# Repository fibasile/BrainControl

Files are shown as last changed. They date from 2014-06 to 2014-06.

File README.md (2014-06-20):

BrainControl
============

Arduino Mind Controlled Robot




Bill of materials
-----------------

- Arduino UNO + Arduino PRO Mini
- MindWave Mobile Bluetooth EEG Headset
- Adafruit Neopixel Ring
- Adafruit LED Matrix
- BlueSmirf Silver Bluetooth
- Pololu Zumo Shield

You can find the PCB schematics in the hardware folder along with files for milling.
You can also build this as a breadboard.

Plans for the lasercut box are included in PDF Format.

Finally the sketches BrainControl and RobotControl must be flashed to the two Arduinos.

License
-------

The MIT License (MIT)

Copyright (c) 2014 Fiore Basile

Permission is hereby granted, free of charge, to any person obtaining a copy
of this software and associated documentation files (the "Software"), to deal
in the Software without restriction, including without limitation the rights
to use, copy, modify, merge, publish, distribute, sublicense, and/or sell
copies of the Software, and to permit persons to whom the Software is
furnished to do so, subject to the following conditions:

The above copyright notice and this permission notice shall be included in
all copies or substantial portions of the Software.

THE SOFTWARE IS PROVIDED "AS IS", WITHOUT WARRANTY OF ANY KIND, EXPRESS OR
IMPLIED, INCLUDING BUT NOT LIMITED TO THE WARRANTIES OF MERCHANTABILITY,
FITNESS FOR A PARTICULAR PURPOSE AND NONINFRINGEMENT. IN NO EVENT SHALL THE
AUTHORS OR COPYRIGHT HOLDERS BE LIABLE FOR ANY CLAIM, DAMAGES OR OTHER
LIABILITY, WHETHER IN AN ACTION OF CONTRACT, TORT OR OTHERWISE, ARISING FROM,
OUT OF OR IN CONNECTION WITH THE SOFTWARE OR THE USE OR OTHER DEALINGS IN
THE SOFTWARE.

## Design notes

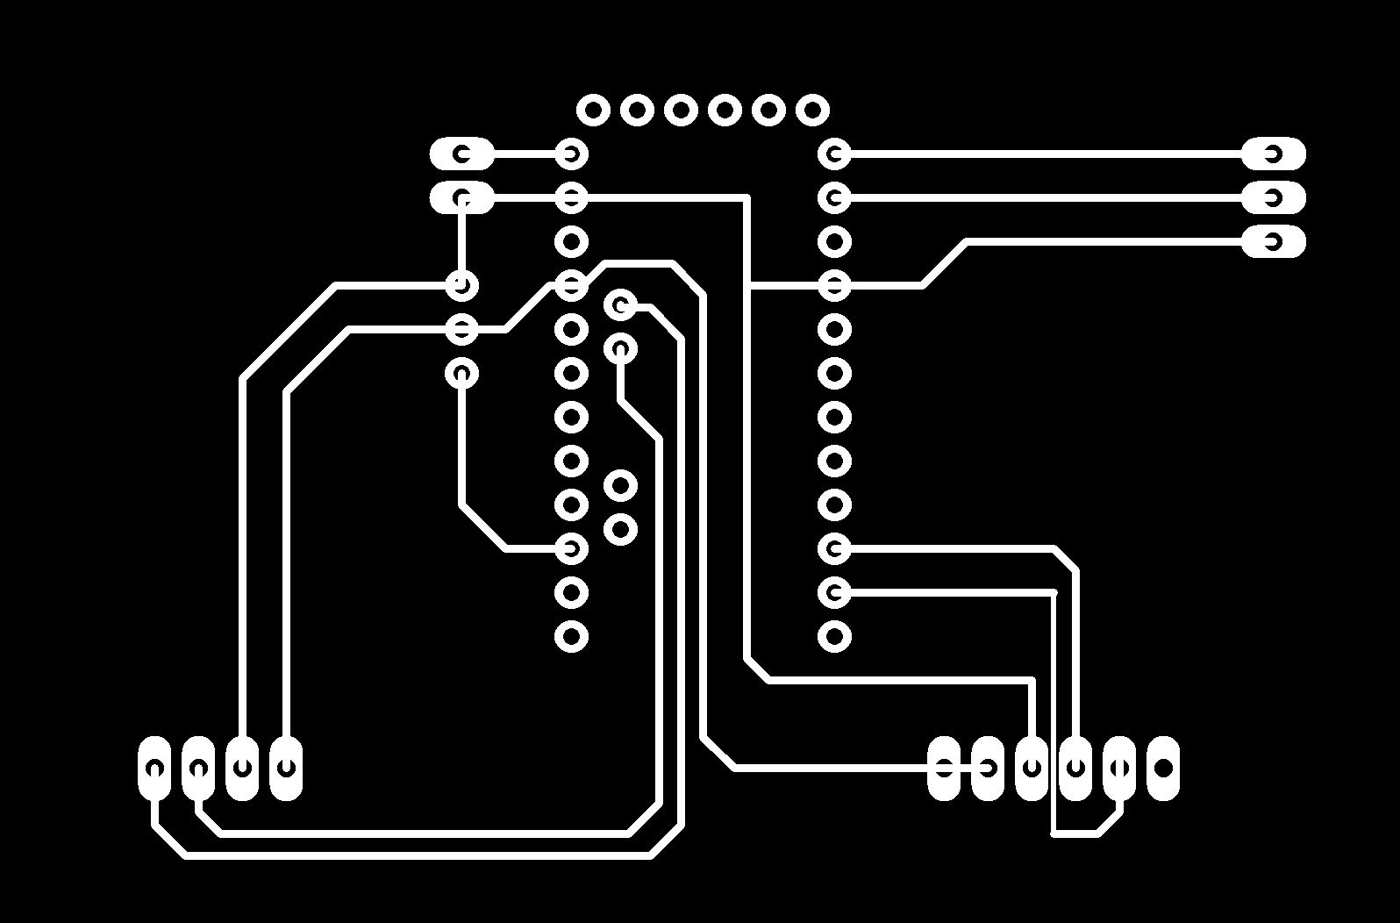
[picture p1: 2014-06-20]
hardware/shield.png

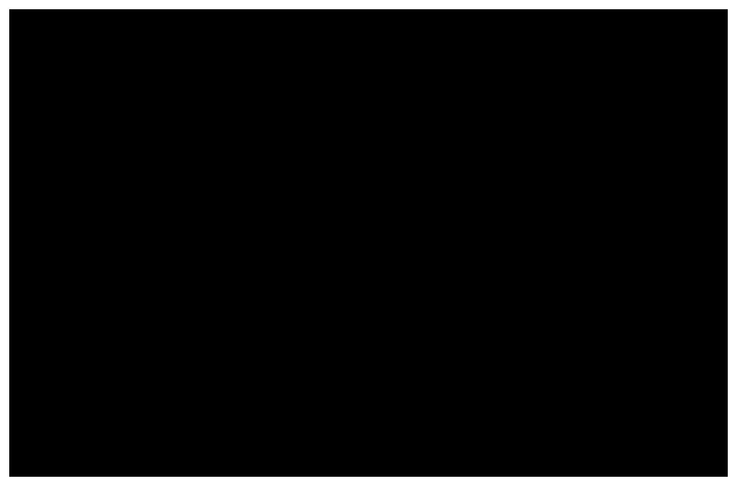
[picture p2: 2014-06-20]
hardware/cutting.png

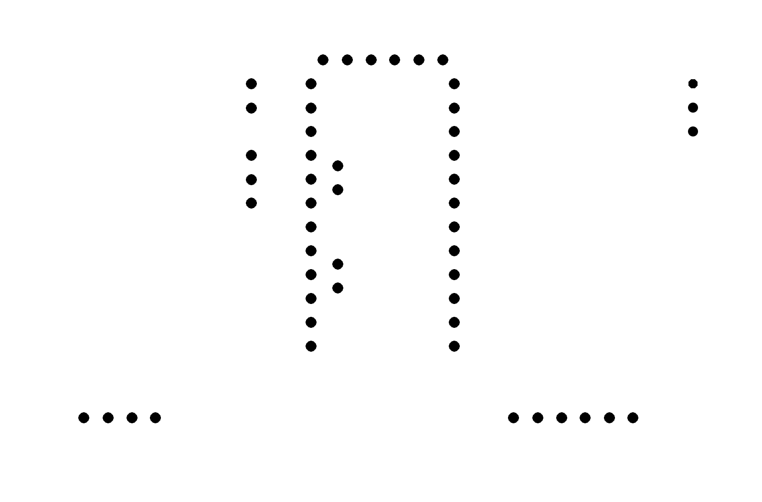
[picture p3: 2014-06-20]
hardware/drilling.png

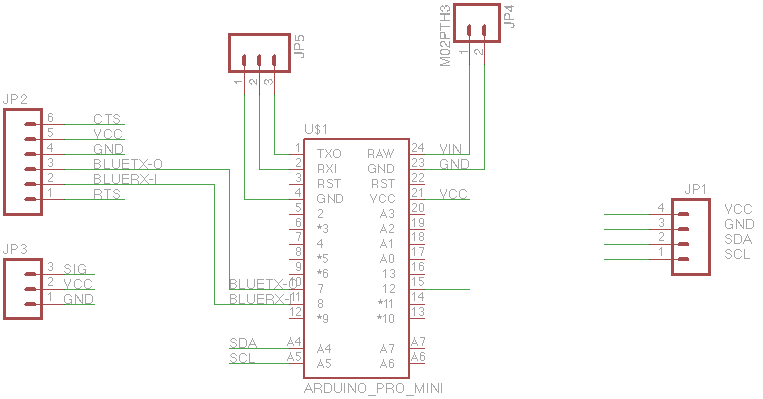
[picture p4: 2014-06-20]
hardware/Schematics.png

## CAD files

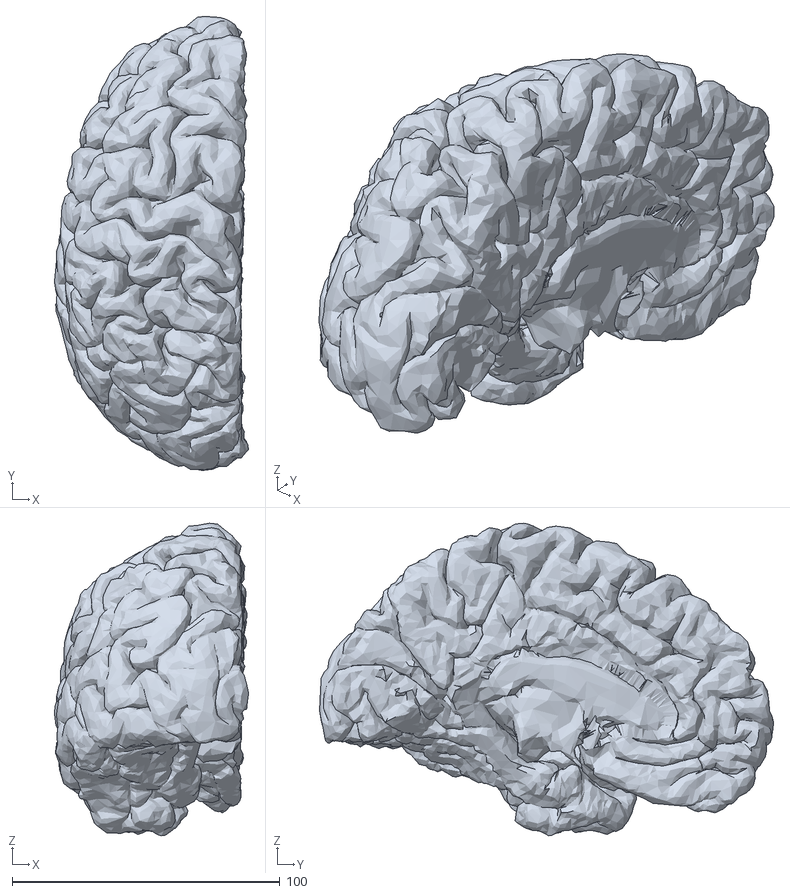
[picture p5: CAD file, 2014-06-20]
hardware/pial_Full_obj/lh.pial_lopoly.stl
72.5 x 169.4 x 116.7

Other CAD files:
hardware/pial_Full_obj/rh.pial_lopoly.stl

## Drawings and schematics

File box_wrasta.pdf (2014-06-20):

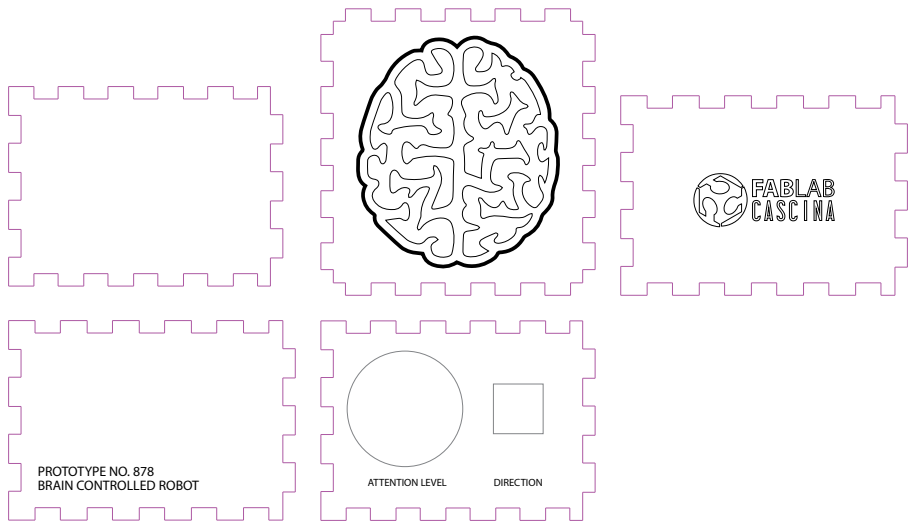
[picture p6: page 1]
ATTENTION LEVEL; DIRECTION BRAIN CONTROLLED ROBOT; PROTOTYPE NO. 878

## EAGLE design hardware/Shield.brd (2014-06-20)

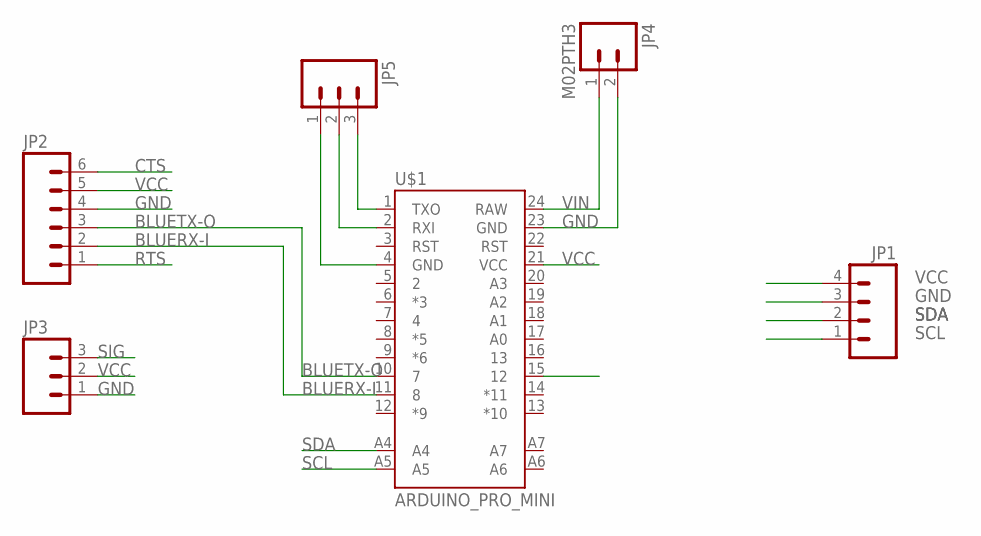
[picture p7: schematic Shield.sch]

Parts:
JP1: M04LONGPADS; 1X04_LONGPADS
JP2: M06LONGPADS; 1X06_LONGPADS
JP3: M03PTH; 1X03
JP4: M02PTH3; 1X02_LONGPADS
JP5: M03LONGPADS; 1X03_LONGPADS
U$1: ARDUINO_PRO_MINI

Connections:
BLUERX-I: JP2.2, U$1.11 (8)
BLUETX-O: JP2.3, U$1.10 (7)
CTS: JP2.6
GND: JP1.3, JP2.4, JP3.1, JP4.2, JP5.1, U$1.4 (GND), U$1.23 (GND)
RTS: JP2.1
RX-I: JP5.2, U$1.2 (RXI)
SCL: JP1.1, U$1.A5
SDA: JP1.2, U$1.A4
SIG: JP3.3, U$1.15 (12)
TX-O: JP5.3, U$1.1 (TXO)
VCC: JP1.4, JP2.5, JP3.2, U$1.21 (VCC)
VIN: JP4.1, U$1.24 (RAW)

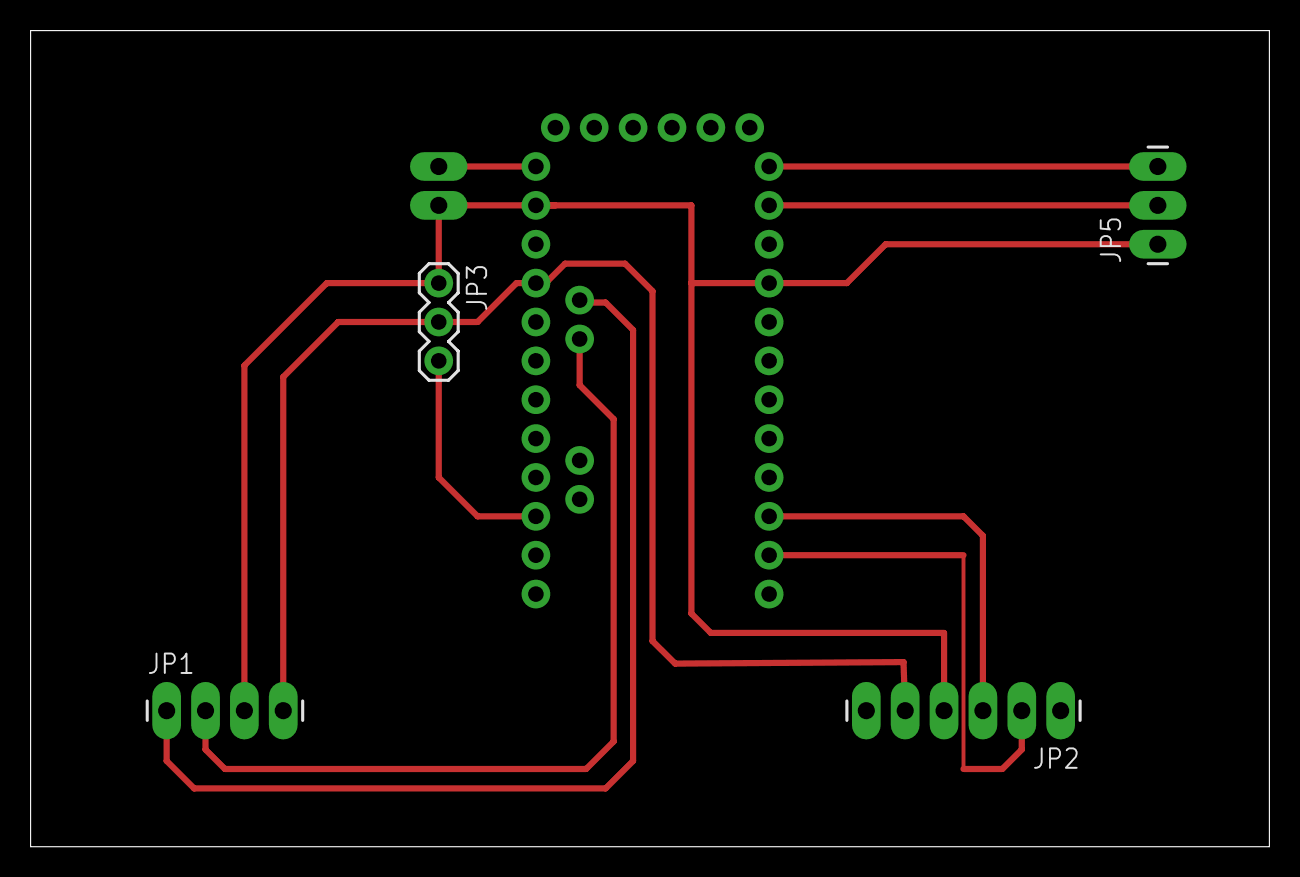
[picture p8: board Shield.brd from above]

Board: 2 copper layers, 81.0 x 53.3 mm, 6 parts (1 on the bottom side), 10 nets.

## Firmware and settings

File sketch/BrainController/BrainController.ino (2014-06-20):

#include <Adafruit_NeoPixel.h>
#include <Wire.h>
#include "Adafruit_LEDBackpack.h"
#include "Adafruit_GFX.h"
#include <SoftwareSerial.h>
//#include <Brain.h>
#include "Mindwave.h"


#define PIXEL_PIN 12
#define PIXEL_COUNT 16

#define DIR_LEFT 0
#define DIR_UP 1
#define DIR_DOWN 2
#define DIR_RIGHT 3

#define DIR_COUNT 5
#define COUNTER 10


int currStep = 0;
int currDir = 0;
int dirSum = 0;
int blink = 0;

Adafruit_NeoPixel strip = Adafruit_NeoPixel(PIXEL_COUNT, PIXEL_PIN, NEO_GRB + NEO_KHZ800);
Adafruit_8x8matrix matrix = Adafruit_8x8matrix();
SoftwareSerial bluetooth(7,8);
Mindwave* brain;

static const uint8_t PROGMEM
  right_bmp[] =
  { B00001000,
    B00001100,
    B00001110,
    B11111111,
    B11111111,
    B00001110,
    B00001100,
    B00001000},
  left_bmp[] = 
  {
    B00010000,
    B00110000,
    B01110000,
    B11111111,
    B11111111,
    B01110000,
    B00110000,
    B00010000},
  up_bmp[] = {
    B00011000,
    B00111100,
    B01111110,
    B11111111,
    B00011000,
    B00011000,
    B00011000,
    B00011000, 
  },
  down_bmp[] = {
    B00011000, 
    B00011000, 
    B00011000, 
    B00011000, 
    B11111111,
    B01111110,
    B00111100,
    B00011000   
  },
  stop_bmp[] = {
    B00111100,
    B01000010,
    B10000001,
    B11111111,
    B11111111,
    B10000001,
    B01000010,
    B00111100    
  };
    
  

void setup(){
  pinMode(7,INPUT);
  pinMode(8,OUTPUT);
  strip.begin();
  clearAttention();
  strip.setBrightness(128);
  strip.show();
  matrix.begin(0x70);
  matrix.drawBitmap(0, 0, stop_bmp, 8, 8, LED_ON);  
  matrix.writeDisplay();
  Serial.begin(57600);
  bluetooth.begin(115200);
  delay(100);  // Short delay, wait for the Mate to send back CMD
  bluetooth.print("$");  // Print three times individually
  bluetooth.print("$");
  bluetooth.print("$");  // Enter command mode
  delay(200);  // Short delay, wait for the Mate to send back CMD
  bluetooth.println("U,9600,N");  // Temporarily Change the baudrate to 9600, no parity
  // 115200 can be too fast at times for NewSoftSerial to relay the data reliably
  bluetooth.begin(9600);  // Start bluetooth serial at 9600
//bluetooth.println("U,115200,N");
  delay(2000);
  bluetooth.println("SR,74E5439C62D3");
  delay(200);
  bluetooth.println("SM,3");
  delay(200);
  bluetooth.println("SP,0000");
  delay(200);
  bluetooth.println("C");
  delay(200);
//  bluetooth.println("U,57600,N");  // Temporarily Change the baudrate to 9600, no parity
//  // 115200 can be too fast at times for NewSoftSerial to relay the data reliably
//  bluetooth.begin(57600);  // Start bluetooth serial at 9600

  delay(2000);
  brain = new Mindwave(bluetooth);
  brain->setup();
  brain->setDebug(false);

}


void clearAttention(){
  for (int i=0; i<PIXEL_COUNT; i++){
     strip.setPixelColor(i, 0,0,0); 
  }
}

void showDirection(int dir){
  matrix.clear();
   switch (dir) {
      case DIR_LEFT:
        matrix.drawBitmap(0, 0, left_bmp, 8, 8, LED_ON);        
        break;
      case DIR_RIGHT:
        matrix.drawBitmap(0, 0, right_bmp, 8, 8, LED_ON);        
        break;
      case DIR_UP:
        matrix.drawBitmap(0, 0, up_bmp, 8, 8, LED_ON);        
        break;
      case DIR_DOWN:
        matrix.drawBitmap(0, 0, down_bmp, 8, 8, LED_ON);        
        break;
      default:
        matrix.drawBitmap(0, 0, stop_bmp, 8, 8, LED_ON);     
        break;
   } 
  matrix.writeDisplay();
}


void showAttention(int maxPix){
  clearAttention();
  for (int i=PIXEL_COUNT-maxPix-1; i<PIXEL_COUNT; i++){
     strip.setPixelColor(i, 0,255,0); 
  }
  strip.show();
}



void loop(){
  brain->update();
  if (brain->hasNewData()) {
        showDirection(currDir);
        dirSum +=  brain->getAttention();
        showAttention(brain->getAttention() / 10);
        blink = brain->getBlink();
//         Serial.print("Blink:");
//         Serial.println(blink);
        currStep++;
  }
  if (currStep > COUNTER) {
     int avg = dirSum / COUNTER;
//     Serial.println("Average ");
//     Serial.print(avg);
      if (avg > 55) {
         for (int k=0;k<3;k++){
           matrix.clear();
           matrix.writeDisplay();
           delay(500);
           showDirection(currDir);
           delay(500);
         }
         Serial.println(currDir);
          
      }
     dirSum = 0;
    currStep = 0;
     currDir++;
     if (currDir >= 5) {
        currDir = 0; 
     }
  }
}

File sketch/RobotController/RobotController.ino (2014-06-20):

#include "ZumoMotors.h"


#define LED_PIN       13 // user LED pin

#define MAX_SPEED             400 // max motor speed
#define PULSE_WIDTH_DEADBAND   25 // pulse width difference from 1500 us (microseconds) to ignore (to compensate for control centering offset)
#define PULSE_WIDTH_RANGE     350 // pulse width difference from 1500 us to be treated as full scale input (for example, a value of 350 means
                                  //   any pulse width <= 1150 us or >= 1850 us is considered full scale)
#define DIR_LEFT 0
#define DIR_UP 1
#define DIR_DOWN 2
#define DIR_RIGHT 3


char inChar;
int left_speed;
int right_speed;

void setup()
{
  Serial.begin(57600);
  pinMode(LED_PIN, OUTPUT);

}

void stop(){
	
	ZumoMotors::setSpeeds(0, 0);	
}

void move(int dir){
	left_speed=0;
	right_speed=0;
	switch (dir){
		case DIR_LEFT:
			left_speed = 0;
			right_speed = 150;
			break;
		case DIR_UP:
			left_speed = 100;
			right_speed = 100;
			break;
		case DIR_DOWN:
			left_speed = -100;
			right_speed = -100;
			break;
		case DIR_RIGHT:
			left_speed =150;
			right_speed = 0;
			break;
		default:
			break;
	}		
        ZumoMotors::setSpeeds(left_speed,right_speed);
	
	delay(2000);
	stop();
}


void loop()
{
	while (Serial.available()){
		inChar = Serial.read();
                Serial.print(inChar);
		switch (inChar){
			case '0':
				move(DIR_LEFT);
				break;
			case '1':
				move(DIR_UP);
				break;
			case '2':
				move(DIR_DOWN);
				break;
			case '3':
				move(DIR_RIGHT);
				break;
			default:
				break;
			
		}
		
	}
}

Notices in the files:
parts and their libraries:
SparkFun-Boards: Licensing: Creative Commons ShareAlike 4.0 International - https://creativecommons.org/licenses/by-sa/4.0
